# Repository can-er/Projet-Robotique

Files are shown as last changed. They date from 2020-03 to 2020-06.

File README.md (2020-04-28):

# A207 Projet-Robotique
## Professeur: COSTA Emile
### Etudiants: ESSALHI Y. - HEMELEERS E. - KORKUT C. - ZEUKENG R.
--------------------------------------------------------------------
> Update 28/04

### Tâches

#### Caner
+ Construction du robot 
+ Elaboration du code source
+ Gestion de la communication et des tâches au sein du groupe
+ Gestion de la plateforme Github
+ Rédaction des rapports 

#### Ronald
+ Construction du robot sur Proteus (simulation) 
+ Elaboration du PCB sur Eagle

#### Younes
+ Elaboration des pièces en 3D sur Fusion360 
+ Elaboration du PCB

#### Emile
+ Elaboration du code source 
+ Coordination de l'équipe

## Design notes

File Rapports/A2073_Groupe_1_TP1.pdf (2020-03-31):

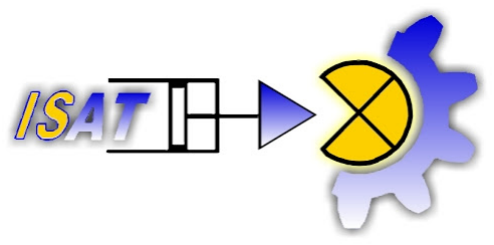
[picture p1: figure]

UE A2073 : Robotique PARTIE II

# Professeur : COSTA Emile

## RAPPORT D’AVANCEMENT

# Etudiants : ESSALHI Younes

# HEMELEERS Emile

# KORKUT Caner

# ZEUKENG Ronald

Seance 1 ´

## Table des matières

1 Introduction | 2
2 Cahier de charges | 2
3 Algorigramme du programme proposé | 4
4 Planning des futures échéances | 5

## 1 Introduction

Dans le cadre de l’UE A2073 : Robotique PARTIE II nous sommes amenés à réaliser un robot mobile sur base d’un cahier de charges. Ce compte-rendu est le premier d’une série de rapports hebdomadaires qui nous permetteront à nous et au professeur de suivre l’avancement du projet. Ce document reprend le cahier de charges, les composants nécessaires au projet, le choix du type d’alimentation, le croquis du travail à réaliser sur Fusion360, un premier algorigramme et enfin un planning pour les futures séances de cours à venir.

## 2 Cahier de charges

Le cahier de charges que nous avons établi se base sur les composants vus en cours et les exigeances du professeur. Il est à noter que nous sommes conscient qu’il ne s’agit que d’un premier jet et que des modifications viendront s’y apporter. Par modifications, nous entendons ajouts de fonctionnalités supplémentaires ou réajustement des objectifs. Voici les fonctionnalités premières qu’assurera notre robot mobile :
- Allumage par RFID du Digispark
- Affichage des états via des LEDs ¹
- Commandé à distance
- Détection d’obstacles
- Blocage des commandes en cas d’obstacle

Nous nous sommes également mis d’accord sur l’ajout de deux fonctionnalités optionnelles en cas d’atteinte prématurée des objectifs. Ainsi, nous aimerions inclure l’utilisation dynamique ² d’un buzzer dans notre robot. La seconde fonc-

tionnalité que nous souhaiterions implémenter est un mode de fonctionnement automatique sans intervention de l’opérateur.

### 2.1 Composants nécessaires

Les éléments que nous avons décidé d’utiliser dans notre robot ne sont autres que ceux qui ont déjà été vus en cours jusqu’ici. Il nous a semblé tout de même

1. Eteint, allumé, connecté, trop proche d’un objet etc
2. Emission d’un son de période variable en fonction de la distance de l’objet pertinent d’énumérer les composants qui feront partie de notre projet :
- LEDs (x10)
- Capteurs ultrason (x4)
- MRFC522
- Moteur DC (x2)
- Pont-H L298N
- Modules bluethoot (x2)
- Interrupteurs électroniques (x4)
- Potentiomètre
- Ecran LCD
- Alimentation

### 2.2 Estimation de la puissance active totale

Sur base des composants actifs cités plus haut, nous avons décidé de passer en revue la puissance qu’ils recquièrent afin de déterminer le type d’alimentation que nous utiliserons.
Tension Courant | Puissance
Détecteur ultra-son 5v | 20mA | 0.1 Watt
moteur DC | 5V | 410mA | 2.0 Watt
LCD | 2.1V | 25mA | 0.1 Watt
RFC522 | 3.3V | 25mA | 0.1 Watt
Arduino Mega | 5V | 13-26mA 2.5 Watt
Digispark | 5V | 500mA | 2.5 Watt
HC-05 | 5V | 30mA | 0.15 Watt
TOTAL | | | ≈ 10W

Une fois la puissance totale nécessaire estimée, nous pouvons passer au choix du type d’alimentation.

### 2.3 Choix du type d’alimentation

Sur base de nos estimations nous avons opté pour une alimentation 5V de type HUB-USB. Nous avons déja entamé les recherches et avons quelques modèles en vue. Voici des alimentations PowerBank pouvant correspondre à nos attentes :

— Anker Batterie Externe, PowerCore Essential 20000
— Mophie Powerstation XXL
— FKANT Batterie Externe 25000mAh
— Pxwaxpy Batterie Externe 26800mAh

— Xiaomi 10,000mAh Mi Power Bank — Sherpa 100AC Portable Power Bank
— RockPals 300W Power Station

Notre choix final se fera en fonction du prix, du poids et de la capacité des chargeurs repris dans cette liste.

### 2.4 Croquis sur Fusion360

## 3 Algorigramme du programme proposé

L’algorigramme que nous avons établi repose sur notre cahier de charges. Tout comme ce dernier, il n’est pas définitif et sera donc adapté en fonction de nos besoins. Nous y avons intégré les fonctionnalités principales de notre programme en faisant abstraction des bibliothèques utilisées.

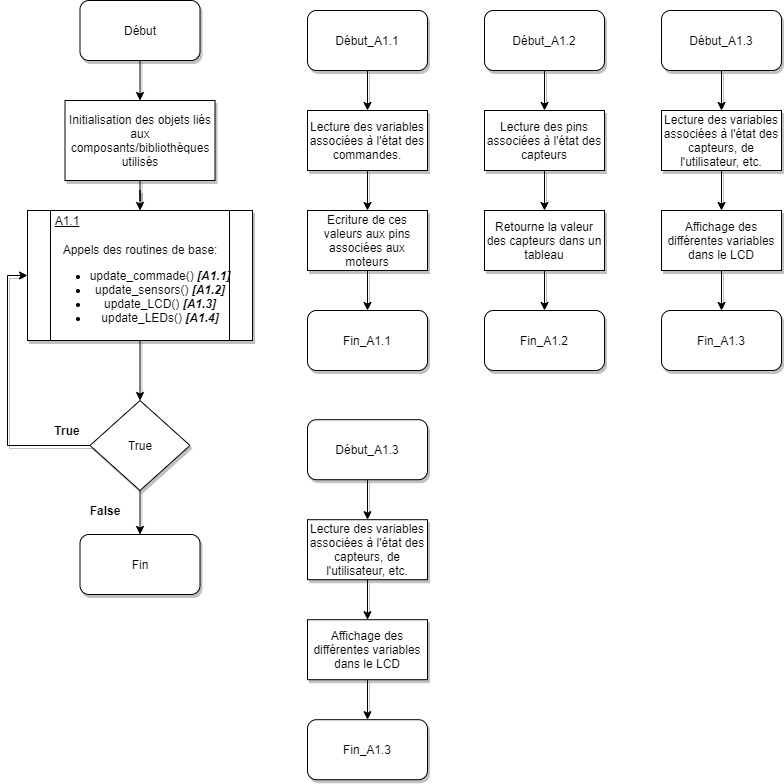
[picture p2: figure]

Cet algorigramme viendra se compléter et donc se voir modifier tout au long de l’avancement du projet. Néanmoins il représente une bonne première ébauche de notre objectif et sera repris pour commencer à rédiger le programme.

## 4 Planning des futures échéances

Dans le cadre du projet nous avons établi une planification des tâches afin de clarifier les objectifs à atteindre par chacun. Il sera sujet pour nous d’être le plus fidèle possible à cet éphéméride et à chacun de rattraper son retard dans le cas échéant. N’ayant que deux heures de séance par semaine prévus pour la réalisation du projet, il nous a semblé indispensable de nous voir en dehors des cours.

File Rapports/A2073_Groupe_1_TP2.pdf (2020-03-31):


UE A2073 : Robotique PARTIE II

# Professeur : COSTA Emile

## RAPPORT D’AVANCEMENT

# Etudiants : ESSALHI Younes

# HEMELEERS Emile

# KORKUT Caner

# ZEUKENG Ronald

Seance II ´

## Table des matières

1 Objectif de la semaine | 2
2 Objectifs atteints | 2
3 Objectifs à venir | 3
A ANNEXE - Code modifié depuis l’exemple de l’IDE Arduino | 4

## 1 Objectif de la semaine

Plusieurs nouvelles idées ont émané suite à notre dernière réunion de groupe :
- Mise en place d’un planning sous Excell ;
- Fixation d’un rendez-vous hebdomadaire (à priori les vendredis) ;
- Nouvelles infos concernant le matériel à utiliser et le schéma Fusion 360 ;
- Mise en ligne du code source dans une plateforme de versionnage (Github) ;
- Création d’un compte GitHub
- Début du prototypage

Ce compte-rendu a pour but de faire le bilan sur les objectifs atteints depuis la dernière séance de cours.

## 2 Objectifs atteints

Tout d’abord nous avons débuté par la mise en place du planning Excell. Après avoir rempli scrupuleusement ce planning, nous avons fixé les vendredis comme étant notre jour de rendez-vous hebdomadaire avant d’optimiser notre travail.

Nous avons également tous pris connaissance de la plateforme Github, y avons créé un compte mais n’avons pas encore créé notre premier répertoire commun.

Nous avons, par groupes de 2, déjà commencé à débuter le développement du robot. Afin de faciliter l’élaboration du projet, nous avons découpé les opérations effectuées par notre robot et sous-problème. Ainsi, un groupe s’est occupé d’intégrer le lecteur RFID à un interrupteur électronique par l’intermédiaire d’un Arduino Mega tandis que le second a mis en place un système de commande de roues dans les deux sens via un Joystick.

Pour commencer, il a été demandé à Ronald et Younes de réaliser un circuit ca-pable de faire tourner les roues dans les deux sens à l’aide d’un Joystick ¹
. Quant
à Caner et Emile, leur tâche fut de commander un interrupteur électronique à l’aide d’un tag RFID unique ²
1. Exemple pris et adapté depuis http ://bit.ly/324RxBj, consulté le 13 février 2020
2. Exemple pris et adapté depuis le site officiel Arduino, consulté le 13 février 2020

Ces deux objectifs ont été atteint et nous pouvons donc dès la prochaine réunion passer à l’assemblage des deux codes.

Pour rappel notre objectif premier est de mettre en place un robot activé par une carte unique et de pouvoir le déplacer avec un Joystick situé dessus. Dans un second temps, nous intégrerons les capteurs et le module Bluethoot.

La maquette sur Fusion360 n’étant pas encore réalisé, nous avons décidé de revoir l’attribution de cette tâche afin d’optimiser notre travail.

## 3 Objectifs à venir

Pour la prochaine séance, les buts que nous nous sommes fixés sommes les suivats :

- Dernière version du planning ;
- Réalisation d’un croquis du PCB à imprimer et avancement sur le croquis ;
- Réalisation d’un mindmap ;
- Intégration des différentes parties de chacun concernant le prototype ;
- Publication de la 1ère version de notre code source sur Github ;
- Début de la communication Bluethoot.

## A ANNEXE - Code modifié depuis l’exemple de

## l’IDE Arduino

1 #i n cl u d e <MFRC522. h>

2
3 | #d e f i n e SS PIN 53
4 | #d e f i n e RST PIN 5

5
6 | b o ol e t a t = 0 ;
7 | i n t start LED = 1 3;

8
9 MFRC522 r f i d ( SS PIN , RST PIN ) ;

10
11 S t ri n g keyOk [ ] = {”69 6d 9d b3” } ;

12
13 | v oid s e tup ( ) {
14 | S e r i a l . b e gi n ( 5 7 6 0 0 ) ;
15 | SPI . b e gi n ( ) ;
16 | r f i d . PCD Init ( ) ;
17 | pinMode ( start LED , OUTPUT) ;

18

19 }

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

25
26 | e l s e {
27 | d i g i t a lW r i t e ( start LED , LOW) ;
28 | }
29 | }
30 | v oid l o o p ( ) {

31
32 | i f ( ! r f i d . PICC IsNewCardPresent ( ) )
33 | r e t u r n ;
34 | i f ( ! r f i d . PICC ReadCardSerial ( ) )
35 | r e t u r n ;

36
37 | S t ri n g myKey = S t ri n g ( r f i d . uid . uidByte [ 0 ] , HEX) + ” ” + S t ri n g ( r f i d
| . uid . uidByte [ 1 ] , HEX) + ” ” + S t ri n g ( r f i d . uid . uidByte [ 2 ] , HEX) +
| ” ” + S t ri n g ( r f i d . uid . uidByte [ 3 ] , HEX) ;

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

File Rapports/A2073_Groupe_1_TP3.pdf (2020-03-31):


## UE A2073 : Robotique PARTIE II

# Professeur : COSTA Emile

# RAPPORT D’AVANCEMENT

# Etudiants : ESSALHI Younes

# HEMELEERS Emile

# KORKUT Caner

# ZEUKENG Ronald

Seance III ´

# 1 Introduction

A l’ordre du jour, nous traiterons les points suivants :
- Réalisation d’un mind map
- Réception et montage d’un second prototype pour les tests à effectuer ;
- Adaptation du code destiné au mouvement du robot ;
- Choix du pont H approprié à notre circuit ;
- Réalisation du travail demandé sur Fusion 360 ;
- Prochains objectifs

Ce compte-rendu a pour but de faire le bilan sur les objectifs atteints depuis la dernière séance de cours et de fixer de nouveaux objectifs à venir.

# 2 Réalisation d’un mind map

Afin d’avoir une vue globale sur le Projet Robotique, nous avons estimé qu’il était nécessaire de faire une carte mentale des informations que nous avions à disposition. Ceci nous sera utile lorsque nous ferons un bilan d’avancement ultérieurement.

Cette carte a été annexée à ce rapport.

# 3 Réception et montage d’un second prototype

# pour les tests à effectuer

Nous avions commandé un second prototype afin d’optimiser les essais. Ainsi, nous pensons avoir un modèle qui sera plus ou moins fixe, où les pièces viendront se rajouter au fur et à mesure tandis que le second prototype servira aux tests. Ce dernier nous servira pour essayer les scripts à la volée, sans que le débranchement d’un composant n’ait d’incidence sur le projet. Il s’agit d’une forme de version-nage hardware auquel nous nous sommes mis d’accord.

Après avoir terminé le projet final, un couvercle viendra se poser sur le robot afin de rendre le visuel plus agréable.

# 4 Adaptation du code destiné au robot

Le code que nous avons pris sur internet ¹
(voir annexesB) nous a permis de faire tourner les roues dans les deux sens et ce à une vitesse variable par l’in-termédiaire du L293D. Cependant, il ne se mouvoient pas à des vitesses indépendantes et cela ne nous permet pas de tourner à gauche ou à droite.

Pour parer à ce problème, nous avons prévu d’adapter le programme fourni.

# 5 Choix du pont H approprié à notre circuit

Pour le choix du pont H destiné aux roues du robot, nous avions le choix entre le L298N et L293D. Après avoir analysé les données techniques liées aux différents composants (voir annexes A), nous avons décidé d’utiliser le L293D pour sa compacité et son faible coût. Cependant, nous n’excluons pas l’utilisation du L298N dans le cas où nos moteurs demanderaient 2 fois plus de courant, où notre pont H dissiperait trop de chaleur, etc...

# 6 Réalisation du travail demandé sur Fusion 360

Pour la conception de notre maquette, nous avons décidé d’utiliser deux plaques entre lesquelles se trouveront les différents composants du robot tels que le moteur, le circuit électrique etc.
Ainsi, sur Fusion 360 nous avons déjà construit certains éléments comme les deux plaques, les roues et les tiges métalliques qui maintiendront les deux plaques, le capteur ultrason, les moteurs DC 5V, l’Arduino, la breadboard.

L’étapes suivante est de de dimensionner parfaitement les composants tel que le circuit électrique imprimé qui se trouvera entres les deux plaques pour pouvoir les dessiner ou choisir sur internet et d’ensuite assembler le tout sur Fusion afin de finaliser la maquette.

Les fichiers sont disponibles en annexe à ce rapport.

1. http ://bit.ly/2Ih4hvm

# 7 Tâches à réaliser pour la prochaine séance

Nous avons constaté que la manière la plus efficace d’atteindre nos objectifs était de travailler par énumération. Par cela, nous entendons qu’en nous fixant des petits objectifs chaque semaine, nous sommes plus efficaces que si nous don-nions une échéance finale pour une date ultérieure. Parmi les prochaines tâches à réaliser, nous pouvons citer les points suivants :

— Faire tourner les roues indépendamment ;
— Intégrer la communication Bluethoot ;
— Intégrer le RFID dans le code avec les mouvements ; — Continuer le travail sur Fusion360
— Décisions à prendre sur le projet final

# A ANNEXE - Datasheet L298N et L293D

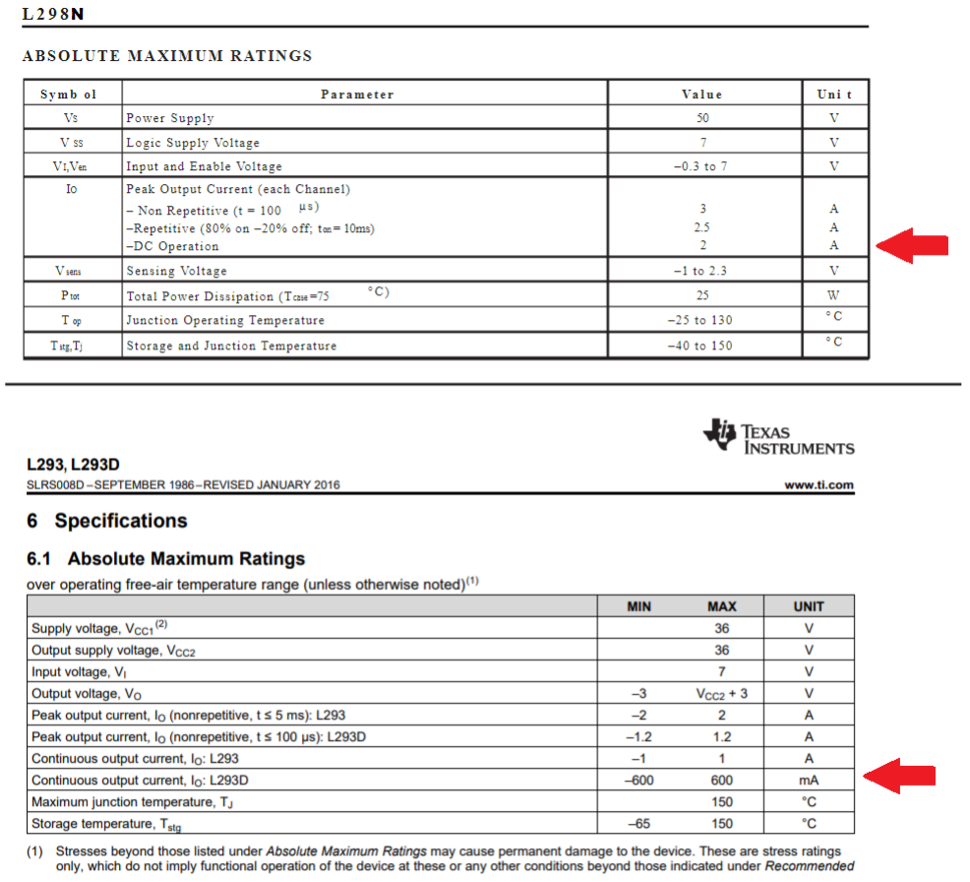
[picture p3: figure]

Figure 1 – Datasheet des deux composants comparés

# B ANNEXE - Code à modifier pris sur Internet

1 | // J o y s ti k
2 | c o n s t i n t JOY ve r tic al = 1 ; // a n al o gi q u e donc A1
3 | c o n s t i n t JOYho rizon tal = 2 ; // a n al o gi q u e donc A2
4 | c o n s t i n t JOYselec t = 2 ; // d i g i t a l 2
5 | i n t j oyV alue = 0 ;
6 | i n t joyValueMax = 1 0 2 3;
7 | i n t joyValueMin = 0 ;
8 | i n t joyValueMid = 5 1 2;
9 | i n t joyValueMidUpper = joyValueMid + 2 0;
10 | i n t joyValueMidLower = joyValueMid − 2 0;

11
12 | //MOTEURS
13 | i n t m o t o r 1 en ablePin = 1 1; //pwm
14 | i n t m o t o r 1 in 1Pin = 1 3;
15 | i n t m o t o r 1 in 2Pin = 1 2;
16 | i n t motor1Speed = 0 ;
17 | i n t motor1SpeedMin = 1 0 0;
18 | i n t motor1SpeedMax = 2 5 5;

19
20 | i n t m o t o r 2 en ablePin = 1 0; //pwm
21 | i n t m o t o r 2 in 1Pin = 8 ;
22 | i n t m o t o r 2 in 2Pin = 7 ;
23 | i n t motor2Speed = 0 ;
24 | i n t motor2SpeedMin = 1 0 0;
25 | i n t motor2SpeedMax = 2 5 5;

26
27 | v oid s e tup ( )
28 | {
29 | // J o y s ti k l e c t u r e
30 | pinMode ( JOYve r tic al , INPUT) ;
31 | pinMode ( JOYhorizontal , INPUT) ;
32 | pinMode ( JOYselect , INPUT) ;
33 | d i g i t a lW r i t e ( JOYselect ,HIGH) ; // p ull −up
34 | S e r i a l . b e gi n ( 9 6 0 0 ) ;

35
36 | //MOTEURS
37 | //on i n i t i a l i s e l e s pi n s du moteur 1
38 | pinMode ( mo to r1 in1Pin , OUTPUT) ;
39 | pinMode ( mo to r1 in2Pin , OUTPUT) ;
40 | pinMode ( m o t o r 1 en ablePin , OUTPUT) ;
41 | //on i n i t i a l i s e l e s pi n s du moteur 2

42 | pinMode ( mo to r2 in1Pin , OUTPUT) ;
43 | pinMode ( mo to r2 in2Pin , OUTPUT) ;
44 | pinMode ( m o t o r 2 en ablePin , OUTPUT) ;
45 | }
46 | v oid l o o p ( )
47 | {
48 | // J o y s ti k
49 | i n t AvAr , GaDr , s e l e c t ;
50 | // l e c t u r e de s v al e u r s du j o y s t i c k
51 | AvAr = analogRead ( JOY ve r tic al ) ; | // e n t r e 0 e t 1023
52 | GaDr = analogRead ( JOYhorizon tal ) ; // e n t r e 0 e t 1023
53 | s e l e c t = di gi t al R e a d ( JOYselec t ) ; | // HIGH ( 1 ) s i non appuye , LOW
( 0 ) si n o n

54
55 | //MOTEURS 1
56 | j oyV alue = analogRead ( JOY ve r tic al ) ;

57
58 | i f ( j oyV alue > joyValueMidUpper ) //Forward
59 | {
60 | motor1Speed = map( joyValue , joyValueMidUpper , joyValueMax ,
motor1SpeedMin , motor1SpeedMax ) ;
61 | Motor1Forward ( motor1Speed ) ;
62 | }
63 | e l s e i f ( j oyV alue < joyValueMidLower ) //Backward
64 | {
65 | motor1Speed = map( joyValue , joyValueMidLower , joyValueMin ,
motor1SpeedMin , motor1SpeedMax ) ;
66 | Motor1Backward ( motor1Speed ) ;
67 | }
68 | // j oyV alue Between joyValueMidLower − joyValueMidUpper .
69 | //Need some r an ge here , bec au se j o y s t i c k sometime not i n | e x a c t
c e n t e r .
70 | e l s e
71 | {
72 | Motor1Stop ( ) ;
73 | }

74
75 | //MOTEURS 2
76 | j oyV alue = analogRead ( JOYho rizon tal ) ;

77
78 | i f ( j oyV alue > joyValueMidUpper ) //Forward
79 | {
80 | motor2Speed = map( joyValue , joyValueMidUpper , joyValueMax ,

motor2SpeedMin , motor2SpeedMax ) ;
81 | Motor2Forward ( motor2Speed ) ;
82 | }
83 | e l s e i f ( j oyV alue < joyValueMidLower ) //Backward
84 | {
85 | motor2Speed = map( joyValue , joyValueMidLower , joyValueMin ,
| motor2SpeedMin , motor2SpeedMax ) ;
86 | Motor2Backward ( motor2Speed ) ;
87 | }
88 | // j oyV alue Between joyValueMidLower − joyValueMidUpper .
89 | //Need some r an ge here , bec au se j o y s t i c k sometime not i n | e x a c t
| c e n t e r .
90 | e l s e
91 | {
92 | Motor2Stop ( ) ;
93 | }
94 | }

95
96 | v oid Motor1Forward ( by te Spd )
97 | {
98 | d i g i t a lW r i t e ( mo to r1 in1Pin , HIGH) ;
99 | d i g i t a lW r i t e ( mo to r1 in2Pin , LOW) ;
100 | an al o gW ri te ( m o t o r 1 en ablePin , Spd ) ;
101 | }
102 | v oid Motor1Backward ( by te Spd )
103 | {
104 | d i g i t a lW r i t e ( mo to r1 in1Pin , LOW) ;
105 | d i g i t a lW r i t e ( mo to r1 in2Pin , HIGH) ;
106 | an al o gW ri te ( m o t o r 1 en ablePin , Spd ) ;
107 | }
108 | v oid Motor1Stop ( )
109 | {
110 | an al o gW ri te ( m o t o r 1 en ablePin , 0 ) ;
111 | }

112
113 | v oid Motor2Forward ( by te Spd )
114 | {
115 | d i g i t a lW r i t e ( mo to r2 in1Pin , HIGH) ;
116 | d i g i t a lW r i t e ( mo to r2 in2Pin , LOW) ;
117 | an al o gW ri te ( m o t o r 2 en ablePin , Spd ) ;
118 | }
119 | v oid Motor2Backward ( by te Spd )
120 | {

121 | d i g i t a lW r i t e ( mo to r2 in1Pin , LOW) ;
122 | d i g i t a lW r i t e ( mo to r2 in2Pin , HIGH) ;
123 | an al o gW ri te ( m o t o r 2 en ablePin , Spd ) ;
124 | }
125 | v oid Motor2Stop ( )
126 | {
127 | an al o gW ri te ( m o t o r 2 en ablePin , 0 ) ;
128 | }

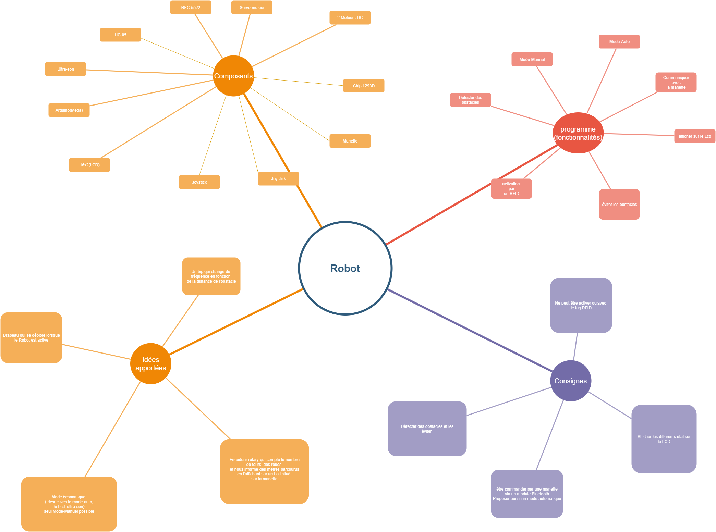
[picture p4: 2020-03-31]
mind_map.png

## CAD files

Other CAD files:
Fusion_360/accroche entre les deux plaquette v2.f3d
Fusion_360/arduino v2.f3d
Fusion_360/bread board v1.f3d
Fusion_360/motor DC 5V v1.f3d
Fusion_360/plaque du dessous v4.f3d

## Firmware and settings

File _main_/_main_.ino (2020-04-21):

/*
L293D *** Arduino
Pin 1 *** Pin 11
Pin 2 *** Pin 12
Pin 3 *** Moteur 1
Pin 4 *** GND
Pin 7 *** Pin 13
Pin 8 *** Pin Vin (9V) fonctionne si vous branchez une pile 9V sur l’arduino au lieu du connecteur USB.
Pin 9 *** Pin 9
Pin 10 *** Pin 7
Pin 11 *** Moteur 2
Pin 12 *** GND
Pin 13 *** GND
Pin 14 *** Moteur 2
Pin 15 *** Pin 8
Pin 16 *** Pin (5V)

commentzire rajouté le 21/04 à 14h50
Bonjour mucho

Joystik *** Arduino
Pin Key *** Pin 2 (numérique côté droite de l’Arduino)
Pin X *** Pin A0
Pin Y *** Pin A1
Pin VCC *** Pin (5V)
Pin GND *** Pin (GND
*/

//Joystik
const int JOYvertical = 1; // analogique donc A1
const int JOYhorizontal = 2; // analogique donc A2
const int JOYselect = 2; // digital 2
int joyValue = 0;
int joyValueMax = 1023;
int joyValueMin = 0;
int joyValueMid = 512;
int joyValueMidUpper = joyValueMid + 20;
int joyValueMidLower = joyValueMid - 20;

//MOTEURS
int motor1_enablePin = 11; //pwm
int motor1_in1Pin = 13;
int motor1_in2Pin = 12;
int motor1Speed = 0;
int motor1SpeedMin = 100;
int motor1SpeedMax = 255;

int motor2_enablePin = 10; //pwm
int motor2_in1Pin = 8;
int motor2_in2Pin = 7;
int motor2Speed = 0;
int motor2SpeedMin = 100;
int motor2SpeedMax = 255;

void setup()
{
  //Joystik lecture
  pinMode(JOYvertical,INPUT);
  pinMode(JOYhorizontal,INPUT);
  pinMode(JOYselect,INPUT);
  digitalWrite(JOYselect,HIGH); // pull-up
  Serial.begin(9600);

  //MOTEURS
  //on initialise les pins du moteur 1
  pinMode(motor1_in1Pin, OUTPUT);
  pinMode(motor1_in2Pin, OUTPUT);
  pinMode(motor1_enablePin, OUTPUT);
  //on initialise les pins du moteur 2
  pinMode(motor2_in1Pin, OUTPUT);
  pinMode(motor2_in2Pin, OUTPUT);
  pinMode(motor2_enablePin, OUTPUT);
}
void loop()
{
  //Joystik
  int AvAr, GaDr, select;
  // lecture des valeurs du joystick
  AvAr = analogRead(JOYvertical);    // entre 0 et 1023
  GaDr = analogRead(JOYhorizontal); // entre 0 et 1023
  select = digitalRead(JOYselect);      // HIGH (1)si non appuye, LOW (0)sinon

//MOTEURS 1
    joyValue = analogRead(JOYvertical);
 
    if(joyValue > joyValueMidUpper) //Forward
    {
        motor1Speed = map(joyValue, joyValueMidUpper, joyValueMax, motor1SpeedMin, motor1SpeedMax);
        Motor1Forward(motor1Speed);
    }
    else if(joyValue < joyValueMidLower) //Backward
    {
        motor1Speed = map(joyValue, joyValueMidLower, joyValueMin, motor1SpeedMin, motor1SpeedMax);
        Motor1Backward(motor1Speed);
    }
    //joyValue Between joyValueMidLower - joyValueMidUpper.
    //Need some range here, because joystick sometime not in  exact center.
    else
    {
       Motor1Stop();
    }

     //MOTEURS 2
    joyValue = analogRead(JOYhorizontal);
 
    if(joyValue > joyValueMidUpper) //Forward
    {
        motor2Speed = map(joyValue, joyValueMidUpper, joyValueMax, motor2SpeedMin, motor2SpeedMax);
        Motor2Forward(motor2Speed);
    }
    else if(joyValue < joyValueMidLower) //Backward
    {
        motor2Speed = map(joyValue, joyValueMidLower, joyValueMin, motor2SpeedMin, motor2SpeedMax);
        Motor2Backward(motor2Speed);
    }
    //joyValue Between joyValueMidLower - joyValueMidUpper.
    //Need some range here, because joystick sometime not in  exact center.
    else
    {
       Motor2Stop();
    }
}

void Motor1Forward( byte Spd)
{
    digitalWrite(motor1_in1Pin, HIGH);
    digitalWrite(motor1_in2Pin, LOW);
    analogWrite(motor1_enablePin, Spd);
}
void Motor1Backward( byte Spd)
{
    digitalWrite(motor1_in1Pin, LOW);
    digitalWrite(motor1_in2Pin, HIGH);
    analogWrite(motor1_enablePin, Spd);
}
void Motor1Stop()
{
    analogWrite(motor1_enablePin, 0);
}

void Motor2Forward( byte Spd)
{
    digitalWrite(motor2_in1Pin, HIGH);
    digitalWrite(motor2_in2Pin, LOW);
    analogWrite(motor2_enablePin, Spd);
}
void Motor2Backward( byte Spd)
{
    digitalWrite(motor2_in1Pin, LOW);
    digitalWrite(motor2_in2Pin, HIGH);
    analogWrite(motor2_enablePin, Spd);
}
void Motor2Stop()
{
    analogWrite(motor2_enablePin, 0);
}

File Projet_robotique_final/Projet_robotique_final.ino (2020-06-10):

#include <MFRC522.h>
#include <Wire.h>
#include <LiquidCrystal_I2C.h>
#include <L298NX2.h>
#include <IRremote.h>

#define LED_VERTE      18
#define LED_ROUGE     17
#define MOTEUR_DROIT   8
#define MOTEUR_GAUCHE  7
#define SS_PIN        53 // RFID (SPI)   
#define RST_PIN        9 // RFID (SPI)
#define TRIGGER_PIN    2 // Broche TRIGGER
#define ECHO_PIN       3
#define RECV_PIN      12 /* Du au mauvais fonctionnement de nos module Bluetooth, nous avons pris une commande infrarouge.*/

// constantes pour la calcul de la distance entre l'obstacle et le capteur HC-SR04
const unsigned long MEASURE_TIMEOUT = 50000UL; // 25ms = ~8m a 340m/s
const float SOUND_SPEED = 340.0 / 1000; //Vitesse du son dans l'air en mm/microsecondes 
int distance_cm;
int distance_obstacle = 50; // distance minimale entre le robot et l'obstacle

//const int RECV_PIN = 12;
IRrecv irrecv(RECV_PIN);
decode_results results;


// initialisation du lecteur UID.
MFRC522 rfid(SS_PIN, RST_PIN);   

//initialisation du bus I2C
LiquidCrystal_I2C lcd(0x27,16,2);


String myKey;   // String retourne par le detecteur UID                
String cmd;


bool Starter_flag = false;       // variable permettant de passer en mode marche grâce à la carte magnetique
bool Turn_flag = false;         // Variable permettant d'entrer dans une boucle pour eviter les obstacles


// Fonciton pour lire l'UID de la carte magnetique

void Find_UID() {
 
  if ( ! rfid.PICC_IsNewCardPresent())    //detecter La carte, si il n'y en a pas on loop tant qu'aucune carte n'est presentee
    return;
  if ( ! rfid.PICC_ReadCardSerial())      // Si il y a une carte, on retourne son nom
    return;

     
  String myKey=String(rfid.uid.uidByte[0],HEX) + " " + String(rfid.uid.uidByte[1],HEX) + " " + String(rfid.uid.uidByte[2],HEX) + " " + String(rfid.uid.uidByte[3],HEX);
  delay(500);

  if ((myKey == "e0 58 45 1a" or "26 5d 5e 34") and (Starter_flag == 0)){   //Condition pour rentrer dans laboucle Starter_flag
  
  Starter_flag = 1;
  delay(100);

  }
  else if ((myKey == "e0 58 45 1a" or "26 5d 5e 34") and (Starter_flag == 1)){ //Condition pour sortir de la boucle Starter_flag
  
  
  Starter_flag = 0;
  }

}

void IR(){ // detection et affichage de la valeur lue envoyee et reçue par infrarouge
  if (irrecv.decode(&results)){
        cmd = String(results.value);
        Serial.println(cmd);
        irrecv.resume();
  }

}

void init_sequence(){

  Serial.begin(9600); //Vitesse de communication pour le port serie
  
  SPI.begin();
  rfid.PCD_Init();
  
  irrecv.enableIRIn();
  irrecv.blink13(true);
  pinMode(LED_VERTE, OUTPUT);
  pinMode(LED_ROUGE, OUTPUT);
  pinMode(MOTEUR_GAUCHE, OUTPUT);
  pinMode(MOTEUR_DROIT, OUTPUT);


  pinMode(TRIGGER_PIN, OUTPUT);
  digitalWrite(TRIGGER_PIN, LOW); // La broche TRIGGER doit etre LOW au repos
  pinMode(ECHO_PIN, INPUT);

  lcd.init(); 
  lcd.backlight();
  lcd.setCursor(0,0);
  lcd.print("----Show ID-----");

}

void wrong_UID_sequence(){
 
 
  lcd.setCursor(0,0);
  lcd.print("----Show ID-----");
  lcd.setCursor(4,1);
  lcd.print("Not ready");
  
  
  Find_UID();
  Serial.print(myKey);
  digitalWrite(LED_VERTE,LOW);
  digitalWrite(LED_ROUGE,HIGH);

  digitalWrite(MOTEUR_GAUCHE, LOW);
  digitalWrite(MOTEUR_DROIT, LOW);

}

void set_directions(){
  // on avance:
  if (cmd == "16718055"){ 
    digitalWrite(MOTEUR_GAUCHE, HIGH);
    digitalWrite(MOTEUR_DROIT, HIGH);      
  }
 // on s'arrete:
  if (cmd == "16726215" or cmd =="4294967295"){ 
    digitalWrite(MOTEUR_GAUCHE, LOW);
    digitalWrite(MOTEUR_DROIT, LOW);
  }
  
  // on tourne a droite:
   if (cmd == "16716015"){ 
    digitalWrite(MOTEUR_GAUCHE, HIGH);
    digitalWrite(MOTEUR_DROIT, LOW); 
  }

  // on tourne a gauche:
   if (cmd == "16734885"){ 
    digitalWrite(MOTEUR_GAUCHE, LOW);
    digitalWrite(MOTEUR_DROIT, HIGH);
  
  
  }  
}


void turn_to_left(){
  digitalWrite(MOTEUR_GAUCHE, LOW);
  digitalWrite(MOTEUR_DROIT, HIGH);
  Turn_flag = 0;
  
}



void setup(){
  init_sequence();
}

void loop(){

  while(!Starter_flag){
    wrong_UID_sequence();  
    Serial.println(Turn_flag);
  }

  while(Starter_flag and !Turn_flag){
    
    
    digitalWrite(LED_ROUGE, LOW);
    digitalWrite(LED_VERTE, HIGH);
    
    lcd.clear();
    lcd.setCursor(0,0);
    lcd.print("-----ID OK------");
    
    digitalWrite(TRIGGER_PIN, HIGH);
    delayMicroseconds(10);
    digitalWrite(TRIGGER_PIN, LOW);
    //Mesure le temps entre l'envoi de l'impulsion ultrasonique et son echo (s'il existe)
    long measure = pulseIn(ECHO_PIN, HIGH, MEASURE_TIMEOUT);
    // Calcule la distance Ã  partir du temps mesure
    float distance_cm = measure / 20.0 * SOUND_SPEED;
    Serial.println(distance_cm);
    delay(200);
    
    Find_UID();
    IR();
    set_directions();    

    if (distance_cm < distance_obstacle){
    Turn_flag = 1;
     }
    Serial.println(Turn_flag); 

    
  }
    if(Turn_flag){

     turn_to_left(); 
      
    }
    
}  
   

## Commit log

2020-04-28 Ajout de fichiers sources
    Fichiers permettant d'envoyer et de recevoir les valeurs du Joystick via bluethoot et de l'afficher sur le terminal
2020-06-10 MAJ code
    Petit problèmes par rapport a quelques trucs mais rien de grave tout est fonctionel
